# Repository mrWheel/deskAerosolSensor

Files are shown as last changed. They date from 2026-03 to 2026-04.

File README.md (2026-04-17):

# SEN66 Dashboard for CYD ILI9341

<div align="center">
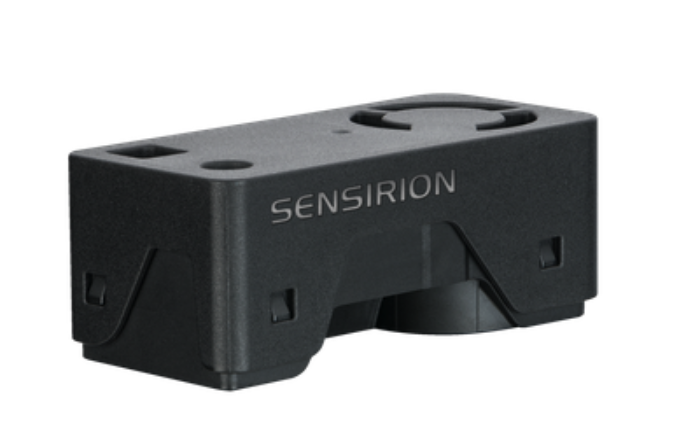
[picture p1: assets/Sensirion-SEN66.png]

</div>

## Disclaimer
This software is developed incrementally. That means I have no clear idea how it works (though it mostly does).

If you have questions about this software, it will probably take you just as long to figure things out as it would take me. So I’d prefer that you investigate it yourself.

Having said that Don’t Even Think About Using It

Seriously. Don’t.

Building this design may injure or kill you during construction, burn your house down while in use, and then—just to be thorough—explode afterward.

This is not a joke. This project involves lethal voltages. If you are not a qualified electronics engineer, close this repository, step away from the soldering iron, and make yourself a cup of tea.

If you decide to ignore all of the above and build it anyway, you do so entirely at your own risk. You are fully responsible for taking proper safety precautions. I take zero responsibility for anything that happens—electrically, mechanically, chemically, spiritually, or otherwise.

Also, full disclosure: I am not a qualified electrical engineer. I provide no guarantees, no warranties, and absolutely no assurance that this design is correct, safe, or suitable for any purpose whatsoever.

## What it is
This PlatformIO project targets a CYD style ESP32 board with an ILI9341 display and a 3x3 LVGL dashboard.
A Desktop device that measures and display the air quality in the room.

<div align="center">
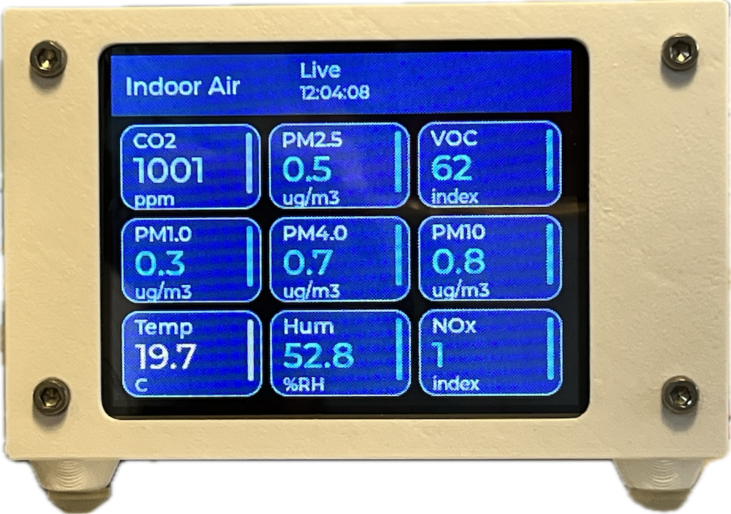
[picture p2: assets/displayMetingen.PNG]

</div>

## Included environments

- `cyd_ili9341`

<div align="center">
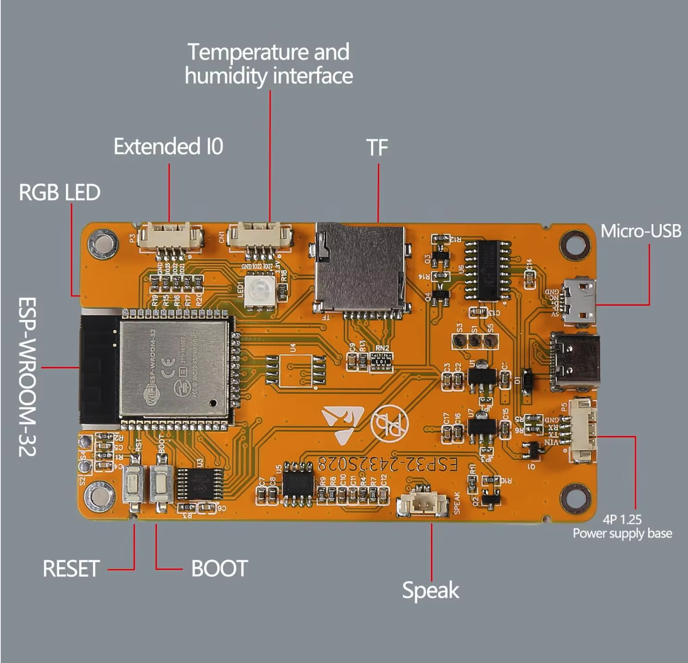
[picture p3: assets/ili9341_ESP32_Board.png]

</div>

  - Main runtime environment for ILI9341
  - Uses the calibrated display configuration
  - `UPDATE_INTERVAL=2500` (milliseconds)
  - `SIMULATION` to show simulated data without using the SEN66

- `ili9341_r4`
  - Display validation environment with `TEST_DISPLAY=1`
  - Shows diagnostic pages (color bars, grid, corner markers, info)

## Display calibration summary

The panel is stable with:

- `CYD_LCD_ROTATION=4`
- `CYD_LCD_PANEL_WIDTH=320`
- `CYD_LCD_PANEL_HEIGHT=240`
- `CYD_LCD_RGB_ORDER=1`

See [ili9341.md](ili9341.md) for full details.

## Sensor wiring for runtime mode

Default I2C pins in `cyd_ili9341`:

- SEN66 VDD -> 3V3
- SEN66 GND -> GND
- SEN66 SDA -> GPIO27
- SEN66 SCL -> GPIO22

<div align="center">
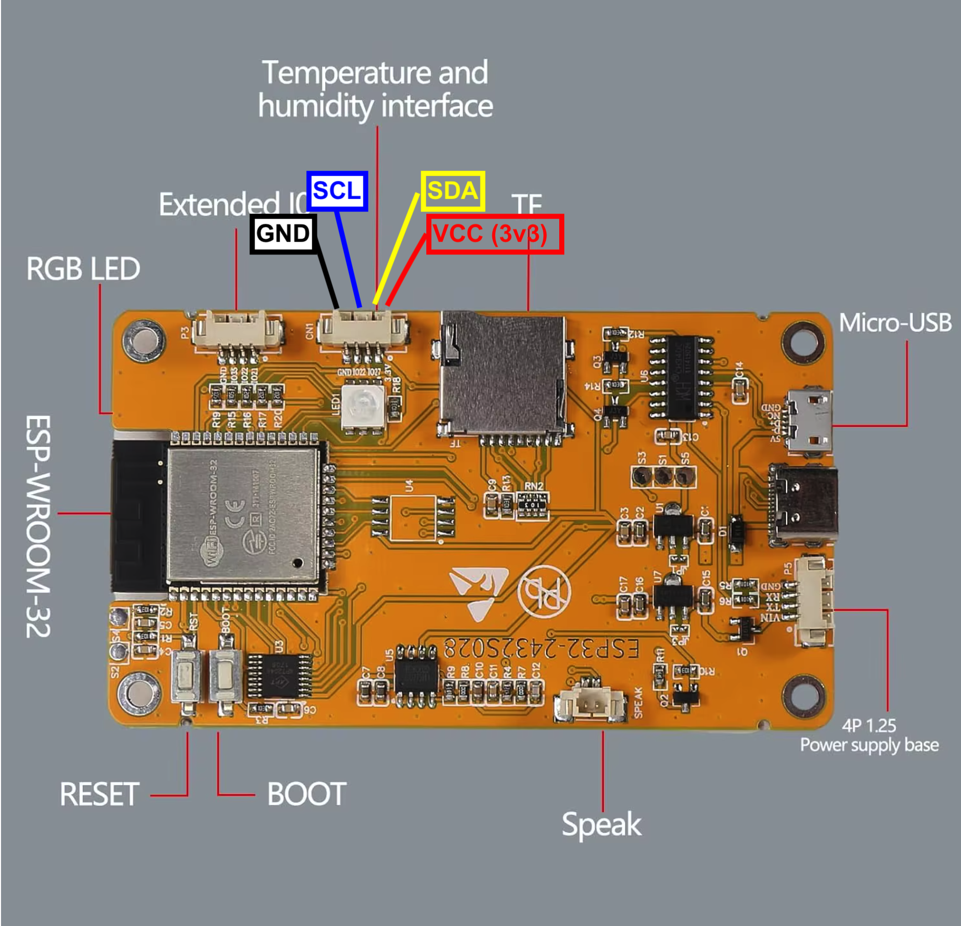
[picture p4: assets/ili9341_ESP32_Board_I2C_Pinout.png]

</div>

Important: on the ILI9341 variant, using GPIO21 for SDA conflicts with the display backlight pin and can make the screen appear black.

## Simulation mode

When `SIMULATION=1` is enabled:

- sensor read logic is skipped
- all nine tiles are updated with synthetic values
- each tile follows a different up/down waveform
- values do not peak at the same time, making color transitions easy to inspect

## Runtime timing

- `UPDATE_INTERVAL` is in milliseconds (ms)
- Set it in `platformio.ini` via build flag, for example:
  - `-D UPDATE_INTERVAL=2500` for 2.5 s
  - `-D UPDATE_INTERVAL=5000` for 5.0 s

The dashboard still shows human-readable time in seconds in the header.

## UI behavior notes

- Header status text uses a fixed position block to avoid left/right jumping when line lengths change.
- The second status line (`Just updated` / `Updated ...`) is tuned to sit close under the first line.
- The existing vertical line at the right side of each tile (LVGL scrollbar part) follows the same color as the tile value.

## MQTT
Measured data is published over MQTT.

WiFi is required before MQTT can connect.

At startup the device first tries stored WiFi credentials. If no credentials are stored, or connection fails, it starts the WiFiManager on-demand captive portal (timeout: 5 minutes).

When the portal starts, the UI and serial output show the AP name to connect to:

- `DAS-a1-2b-3c`

Where `a1`, `2b`, and `3c` are the last three bytes of the ESP32 MAC address.

The WiFi/MQTT portal logic is implemented in:

- `WiFiManagerExt.h`
- `WiFiManagerExt.cpp`

Portal fields:

- MQTT broker URL
- MQTT username (optional)
- MQTT password (optional)
- MQTT broker port (`1883` for plain MQTT, `8883` for TLS)
- MQTT topic (default: AP name + `/data`, for example `DAS-a1-2b-3c/data`)
- MQTT publish interval (ms)

```
{"pm1_0":0.6,"pm2_5":1.0,"pm4_0":1.3,"pm10":1.5,"humidity":52.6,"temperature":17.7,"voc":68,"nox":1,"co2":1372,"timeStamp":"2026-03-28T15:24:41+0100"}
{"pm1_0":0.6,"pm2_5":1.0,"pm4_0":1.3,"pm10":1.5,"humidity":52.6,"temperature":17.7,"voc":68,"nox":1,"co2":1371,"timeStamp":"2026-03-28T15:24:51+0100"}
{"pm1_0":0.6,"pm2_5":1.0,"pm4_0":1.3,"pm10":1.5,"humidity":52.6,"temperature":17.6,"voc":68,"nox":1,"co2":1367,"timeStamp":"2026-03-28T15:25:01+0100"}
```
These values are persisted and shown again as defaults in the portal.
If no topic was saved yet, or the saved topic is empty, the default topic is `DAS-xx-yy-zz/data` based on the last three MAC bytes.

If GPIO0 is held low for longer than 10 seconds, stored WiFi settings are cleared and the device restarts (`ESP.restart()`).

### MQTT payload

Each publish sends one JSON object with the latest sample, for example:

```json
{
  "pm1_0": 7.3,
  "pm2_5": 12.8,
  "pm4_0": 16.2,
  "pm10": 22.1,
  "humidity": 45.6,
  "temperature": 20.4,
  "voc": 103,
  "nox": 84,
  "co2": 721,
  "timestamp": 2026-03-28T15:24:41+0100
}
```

## Build and upload

Examples:

- Build main runtime:
  - `platformio run -e cyd_ili9341`
- Upload main runtime:
  - `platformio run -e cyd_ili9341 --target upload`
- Build display test:
  - `platformio run -e ili9341_r4`

## Dashboard tiles

- CO2
- PM2.5
- VOC
- PM1.0
- PM4.0
- PM10
- Temp
- Hum
- NOx

Tile value colors move from cooler (blue) to warmer tones (red) as badness increases.

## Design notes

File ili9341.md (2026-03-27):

# ILI9341 on CYD (ESP32) - Final Working Notes

This file captures the latest proven display setup used in this repository.

## 1. Hardware profile

- Board class: ESP32 CYD style board with 2.8 inch panel
- Display controller: ILI9341
- SPI host: VSPI
- SPI and control pins:
  - SCLK = 14
  - MOSI = 13
  - MISO = 12
  - DC = 2
  - CS = 15
  - Backlight = 21

## 2. Required panel geometry and orientation

The panel works correctly with these settings:

- panel width = 320
- panel height = 240
- memory width = 320
- memory height = 240
- rotation = 4
- RGB order = true

Without explicit memory width and memory height, the panel can show shifted or wrapped output in some rotation combinations.

## 3. LovyanGFX panel configuration

Use this configuration pattern:

```cpp
auto config = panel.config();
config.pin_cs = 15;
config.pin_rst = -1;
config.pin_busy = -1;

config.panel_width = 320;
config.panel_height = 240;
config.memory_width = 320;
config.memory_height = 240;

config.offset_x = 0;
config.offset_y = 0;
config.offset_rotation = 0;

config.rgb_order = true;
config.invert = false;
```

And set:

```cpp
tft.setRotation(4);
```

## 4. SPI bus settings

Stable settings in this project:

```cpp
auto busCfg = bus.config();
busCfg.spi_host = VSPI_HOST;
busCfg.spi_mode = 0;
busCfg.freq_write = 40000000;
busCfg.freq_read = 16000000;
busCfg.spi_3wire = false;
busCfg.use_lock = true;
busCfg.dma_channel = SPI_DMA_CH_AUTO;
```

## 5. LVGL flush path that worked reliably

The final working flush path uses `pushImage`:

```cpp
tft.startWrite();
tft.pushImage(area->x1, area->y1, width, height, reinterpret_cast<lgfx::rgb565_t*>(colorMap));
tft.endWrite();
```

LVGL resolution is derived from the active display object (`tft.width()`, `tft.height()`).

## 6. Current environments

This repository intentionally keeps two environments:

- `cyd_ili9341`
  - Full dashboard build for ILI9341
  - Currently configured with `SIMULATION=1`
- `ili9341_r4`
  - Display-only test pattern mode (`TEST_DISPLAY=1`)

## 7. SIMULATION mode behavior

With `SIMULATION=1`:

- sensor reading is skipped
- all nine tiles update continuously
- values move slowly up and down
- each tile uses a different period and phase so peaks do not happen at the same time
- serial monitor prints periodic simulation snapshots

## 8. Quick display verification

In `ili9341_r4` test mode, verify:

- color bars are in logical order
- corner markers are in expected corners
- text is readable and not mirrored

## 9. Practical note on borders

A small inactive black edge can still be normal panel dead area near the FPC side and is not always removable in software.

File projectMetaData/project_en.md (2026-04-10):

# Desktop Air Quality Monitor

This project turns an ***Cheap Yellow Display*** into a live indoor air quality 
dashboard using a SEN66 sensor and a color-coded 3x3 tile interface.
It continuously shows particulate matter (PM1.0, PM2.5, PM4.0, PM10), CO2, 
VOC index, NOx index, temperature, and humidity.

A clear startup flow handles connectivity, sensor warm-up, and status 
feedback directly on screen.
If no network is available, a captive WiFi portal allows configuration 
without reflashing.
When configured, measurements can be published as JSON messages to an MQTT 
broker at a chosen interval.
Time synchronization enables reliable timestamps for telemetry and diagnostics.

A simulation mode is included to validate dashboard behavior without physical 
sensor input.

The result is a practical, readable, and deployable desktop monitor for 
real-time environmental awareness.

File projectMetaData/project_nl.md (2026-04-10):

# Desktop Luchtkwaliteit Meter

Dit project maakt met een ***Cheap Yellow Display*** een live dashboard voor
binnenluchtkwaliteit met een SEN66-sensor en een kleurgecodeerde 
3x3 tegelweergave.
Het systeem toont continu fijnstofwaarden (PM1.0, PM2.5, PM4.0, PM10), CO2,
VOC-index, NOx-index, temperatuur en luchtvochtigheid.

Een duidelijke opstartflow begeleidt netwerkverbinding, sensor-opwarming en statusmeldingen rechtstreeks op het scherm.
Als er nog geen netwerk is ingesteld, kan configuratie via een captive WiFi-portaal
gebeuren zonder opnieuw te flashen.
Wanneer geconfigureerd, worden metingen als JSON-berichten naar een MQTT-broker
verstuurd op een instelbaar interval.
Tijdsynchronisatie zorgt voor bruikbare tijdstempels in telemetrie en diagnose.

Er is ook een simulatiemodus voorzien om de dashboardlogica te testen zonder 
fysieke sensorinput.

Het resultaat is een praktisch, leesbaar en inzetbaar desktopmonitoringsysteem 
voor realtime omgevingsinzichten.

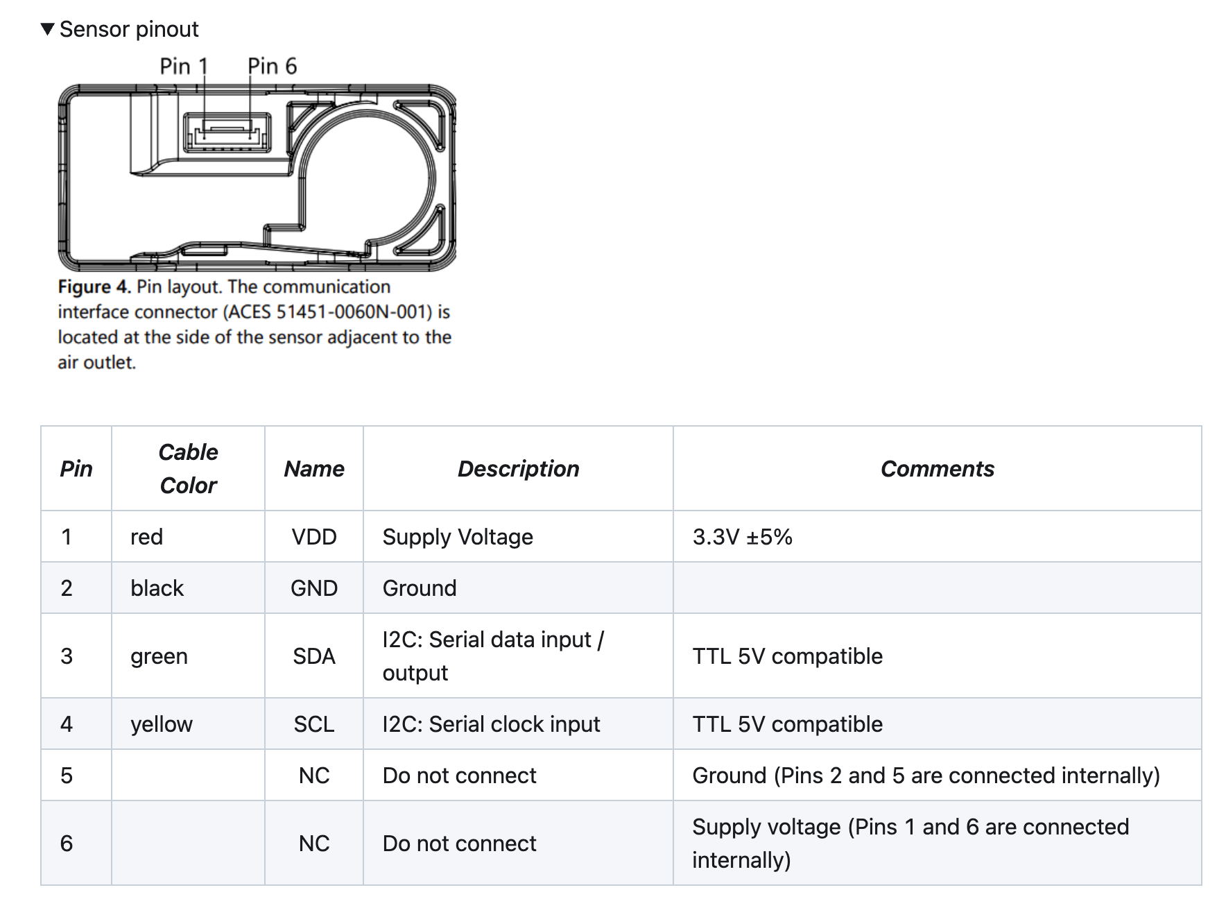
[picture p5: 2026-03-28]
assets/SEN66_Pinout.png

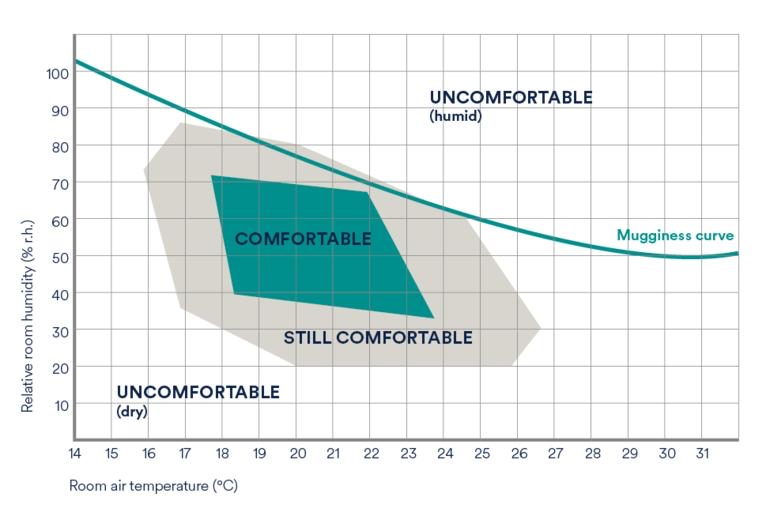
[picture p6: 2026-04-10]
assets/TemperatureConfort.png

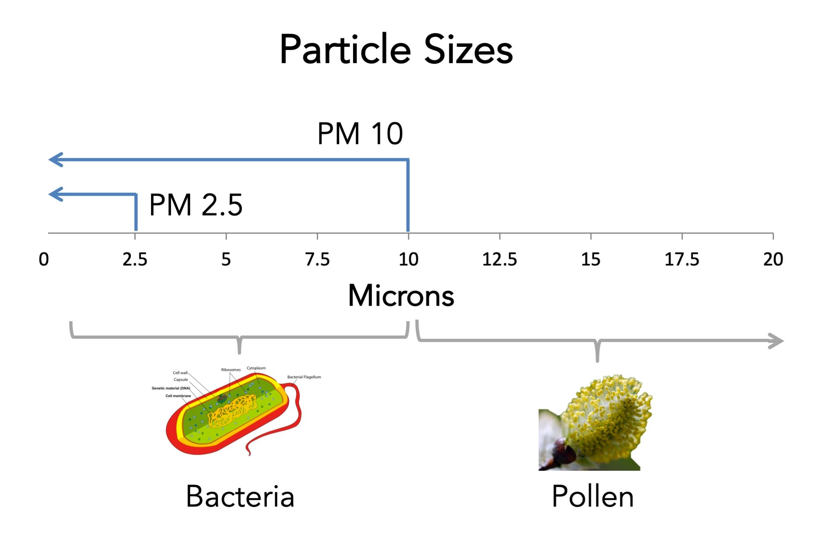
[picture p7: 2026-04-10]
assets/particleSizes.png

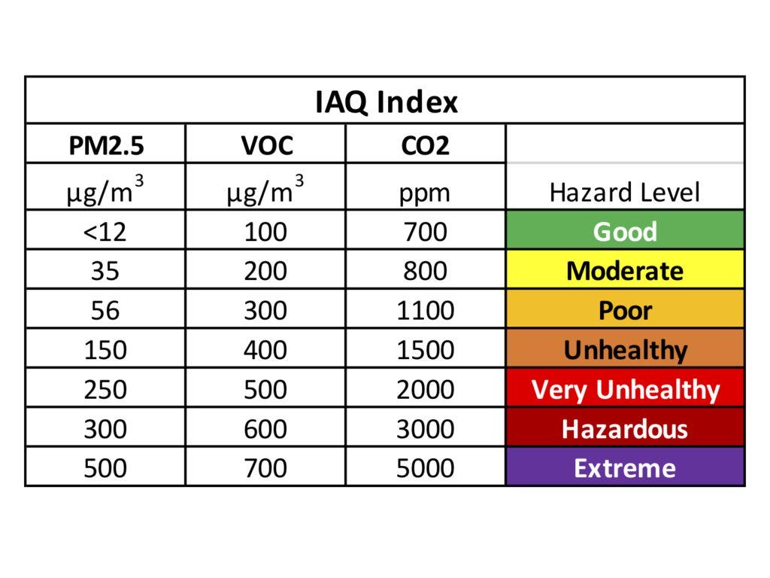
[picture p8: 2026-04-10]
assets/IAQ_Index.png

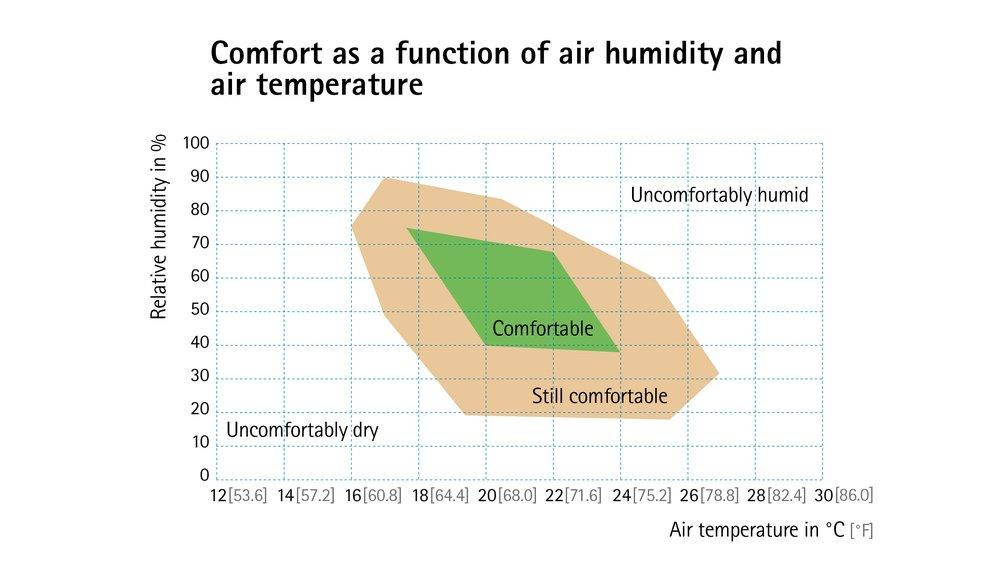
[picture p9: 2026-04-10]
assets/HumidetyConfort.png

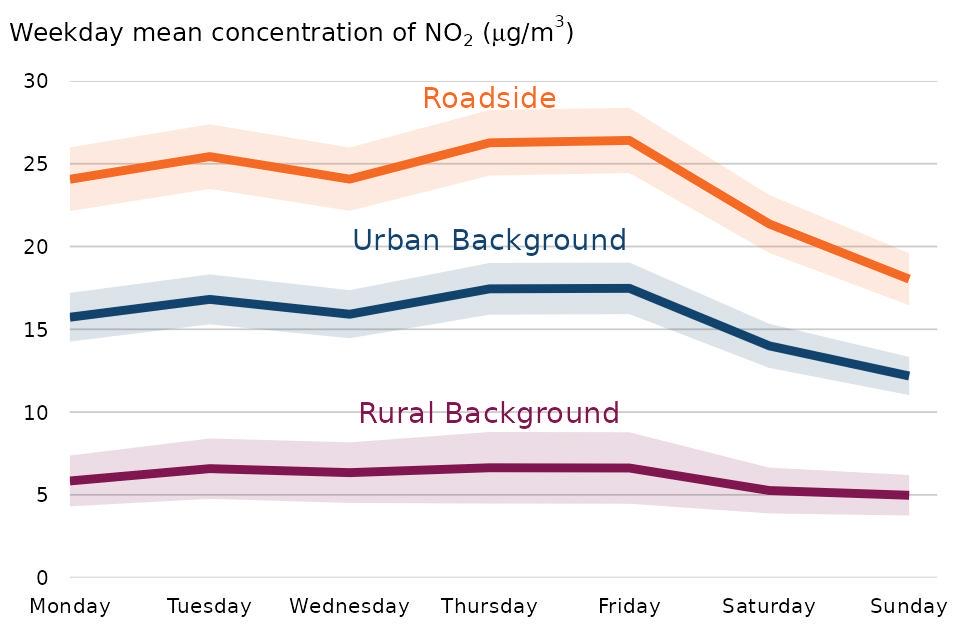
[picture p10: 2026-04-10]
assets/NO2_Index.png

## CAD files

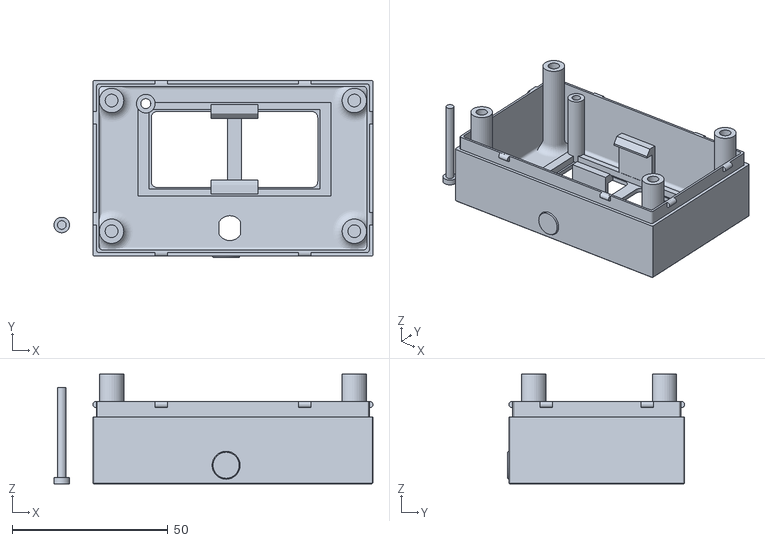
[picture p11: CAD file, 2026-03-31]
3D/deskAerosolSensorBase.stl
102.5 x 57.0 x 35.3

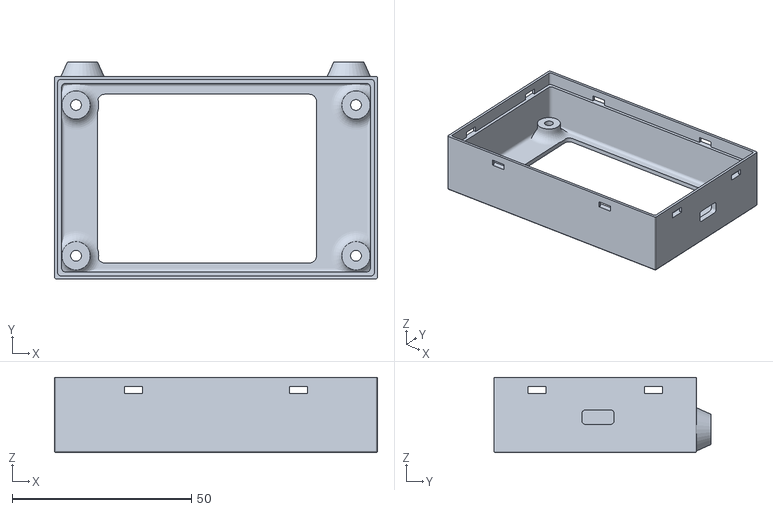
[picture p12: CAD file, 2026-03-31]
3D/deskAerosolSensorLid.stl
90.0 x 60.5 x 21.0

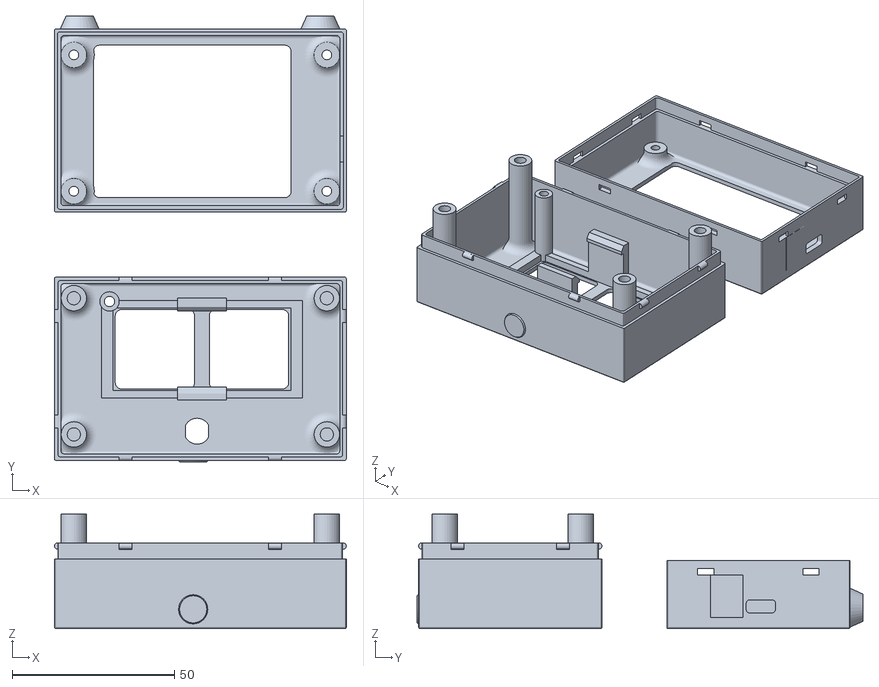
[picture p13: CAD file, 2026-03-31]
3D/deskAerosolSensor.stl
90.1 x 137.5 x 35.3

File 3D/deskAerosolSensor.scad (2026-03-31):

//-----------------------------------------------------------------------
// Yet Another Parameterized Projectbox generator
//
//  This is a box for timerModule HCW-M421
//
//  Version 1.0.0 (2026-02-17)
//
// This design is parameterized based on the size of a PCB.
//
// For many/complex cutoutGrills, you might need to adjust
//  the max number of elements in OpenSCAD:
//
//      Preferences->Advanced->Turn off rendering at 250000 elements
//                                                   ^^^^^^
//
//-----------------------------------------------------------------------


include <./YAPPgenerator_v3.scad>

//---------------------------------------------------------
// This design is parameterized based on the size of a PCB.
//---------------------------------------------------------
// Note: length/lengte refers to X axis, 
//       width/breedte refers to Y axis,
//       height/hoogte refers to Z axis

/*
      padding-back|<------pcb length --->|<padding-front
                            RIGHT
        0    X-axis ---> 
        +----------------------------------------+   ---
        |                                        |    ^
        |                                        |   padding-right 
      Y |                                        |    v
      | |    -5,y +----------------------+       |   ---              
 B    a |         | 0,y              x,y |       |     ^              F
 A    x |         |                      |       |     |              R
 C    i |         |                      |       |     | pcb width    O
 K    s |         |                      |       |     |              N
        |         | 0,0              x,0 |       |     v              T
      ^ |    -5,0 +----------------------+       |   ---
      | |                                        |    padding-left
      0 +----------------------------------------+   ---
        0    X-as --->
                          LEFT
*/


//-- which part(s) do you want to print?
printBaseShell        = true;
printLidShell         = false;
printSwitchExtender   = true;
printDisplayClips     = false;

// ********************************************************************
// The Following will be used as the first element in the pbc array

//Defined here so you can define the "Main" PCB using these if wanted
pcbLength           =  86; // front to back (X axis)
pcbWidth            =  50; // side to side (Y axis)
pcbThickness        = 1.6; 
standoffHeight      = 3.0; //-- How much the PCB needs to be raised from the base to leave room for solderings and whatnot
standoffDiameter    = 3;
standoffPinDiameter = 2.2;
standoffHoleSlack   = 0.2;

//===================================================================
// *** PCBs ***
// Printed Circuit Boards
//-------------------------------------------------------------------
//  Default origin =  yappCoordPCB : yappCoordBoxInside[0,0,0]
//
//  Parameters:
//   Required:
//    p(0) = name
//    p(1) = length
//    p(2) = width
//    p(3) = posx
//    p(4) = posy
//    p(5) = Thickness
//    p(6) = standoff_Height = Height to bottom of PCB from the inside of the base
//             negative measures from inside of the lid to the top of the PCB
//    p(7) = standoff_Diameter
//    p(8) = standoff_PinDiameter
//   Optional:
//    p(9) = standoff_HoleSlack (default to 0.4)

//The following can be used to get PCB values elsewhere in the script - not in pcb definition. 
//If "PCB Name" is omitted then "Main" is used
//  pcbLength           --> pcbLength("PCB Name")
//  pcbWidth            --> pcbWidth("PCB Name")
//  pcbThickness        --> pcbThickness("PCB Name") 
//  standoffHeight      --> standoffHeight("PCB Name") 
//  standoffDiameter    --> standoffDiameter("PCB Name") 
//  standoffPinDiameter --> standoffPinDiameter("PCB Name") 
//  standoffHoleSlack   --> standoffHoleSlack("PCB Name") 

pcb = 
[
  // Default Main PCB - DO NOT REMOVE the "Main" line.
  ["Main",  pcbLength,pcbWidth, 0, 0, pcbThickness
          , standoffHeight
          , standoffDiameter
          , standoffPinDiameter
          , standoffHoleSlack]
];

//-------------------------------------------------------------------                            
//-- padding between pcb and inside wall
paddingFront        = 0;
paddingBack         = 0;
paddingRight        = 0.5;
paddingLeft         = 2;

//-- Edit these parameters for your own box dimensions
wallThickness       = 2.0;
basePlaneThickness  = 1.5;
lidPlaneThickness   = 1.5;

//-- Total height of box = lidPlaneThickness 
//                       + lidWallHeight 
//--                     + baseWallHeight 
//                       + basePlaneThickness
//-- space between pcb and lidPlane :=
//--      (bottonWallHeight+lidWallHeight) - (standoffHeight+pcbThickness)
baseWallHeight      = 25;
lidWallHeight       = 15;

//-- ridge where base and lid off box can overlap
//-- Make sure this isn't less than lidWallHeight
ridgeHeight         = 5.0;
ridgeSlack          = 0.4; // Gap between the inside of the lid and the outside of the base
//New in v3.3.7 
ridgeGap            = 0.5; // Gap between the bottom of the base ridge and the bottom of the lid when assembled.
roundRadius         = 0.5;

// Box Types are 0-4 with 0 as the default
// 0 = All edges rounded with radius (roundRadius) above
// 1 = All edges sqrtuare
// 2 = All edges chamfered by (roundRadius) above 
// 3 = Square top and bottom edges (the ones that touch the build plate) and rounded vertical edges
// 4 = Square top and bottom edges (the ones that touch the build plate) and chamfered vertical edges
// 5 = Chanfered top and bottom edges (the ones that touch the build plate) and rounded vertical edges
boxType             = 0; // Default type 0

// Set the layer height of your printer
printerLayerHeight  = 0.2;


//---------------------------
//--     C O N T R O L     --
//---------------------------
// -- Render --
renderQuality             = 8;          //-> from 1 to 32, Default = 8
$fn=30;
// --Preview --
previewQuality            = 5;          //-> from 1 to 32, Default = 5
showSideBySide            = true;       //-> Default = true
onLidGap                  = 0;  // tip don't override to animate the lid opening
colorLid                  = "YellowGreen";   
alphaLid                  = 1;
colorBase                 = "BurlyWood";
alphaBase                 = 1;
hideLidWalls              = true;      //-> Remove the walls from the lid : only if preview and showSideBySide=true 
hideBaseWalls             = true;      //-> Remove the walls from the base : only if preview and showSideBySide=true  
showOrientation           = true;       //-> Show the Front/Back/Left/Right labels : only in preview
showPCB                   = false;      //-> Show the PCB in red : only in preview 
showSwitches              = false;      //-> Show the switches (for pushbuttons) : only in preview 
showButtonsDepressed      = false;      //-> Should the buttons in the Lid On view be in the pressed position
showOriginCoordBox        = false;      //-> Shows red bars representing the origin for yappCoordBox : only in preview 
showOriginCoordBoxInside  = false;      //-> Shows blue bars representing the origin for yappCoordBoxInside : only in preview 
showOriginCoordPCB        = false;      //-> Shows blue bars representing the origin for yappCoordBoxInside : only in preview 
showMarkersPCB            = false;      //-> Shows black bars corners of the PCB : only in preview 
showMarkersCenter         = false;      //-> Shows magenta bars along the centers of all faces  
inspectX                  = 0;          //-> 0=none (>0 from Back)
inspectY                  = 0;          //-> 0=none (>0 from Right)
inspectZ                  = 0;          //-> 0=none (>0 from Bottom)
inspectXfromBack          = true;       //-> View from the inspection cut foreward
inspectYfromLeft          = true;       //-> View from the inspection cut to the right
inspectZfromBottom        = true;       //-> View from the inspection cut up
//---------------------------
//--     C O N T R O L     --
//---------------------------

//-------------------------------------------------------------------
//-------------------------------------------------------------------
// Start of Debugging config (used if not overridden in template)
// ------------------------------------------------------------------
// ------------------------------------------------------------------
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

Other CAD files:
3D/YAPP_Template_v3.scad
3D/YAPPgenerator_v3.scad

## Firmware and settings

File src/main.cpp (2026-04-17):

/*** Last Changed: 2026-04-17 - 08:38 ***/
#include <Arduino.h>
#include <Wire.h>
#include <lvgl.h>
#include <math.h>
#include <time.h>
#include <WiFi.h>
#include <WiFiClientSecure.h>
#include <PubSubClient.h>
#include "appConfig.h"
#include "dashboardUi.h"
#include "displayDriver.h"
#include "sensorReader.h"
#include "WiFiManagerExt.h"

const char* PROG_VERSION = "v1.1.1";

//--- Global objects
static DashboardUi dashboardUi;
static DisplayDriver displayDriver;
static SensorReader sensorReader;
static WiFiManagerExt wifiManagerExt;
static SensorData sensorData = {};
static bool sensorOnline = false;
static bool mqttEnabled = false;
static bool wifiReady = false;
static bool tilesVisible = false;
static uint32_t sensorStartMs = 0;
static uint32_t lastSensorReadMs = 0;
static uint32_t lastSensorRetryMs = 0;
static uint32_t lastMqttConnectTryMs = 0;
static uint32_t lastMqttPublishMs = 0;
static uint32_t lastTimeSyncTryMs = 0;
static uint32_t mqttStatusFlashUntilMs = 0;
static constexpr uint32_t kSensorRetryIntervalMs = 5000;
static constexpr uint32_t kMqttRetryIntervalMs = 5000;
static constexpr uint32_t kTimeSyncRetryMs = 60000;
static constexpr uint32_t kMqttStatusFlashMs = 800;
static bool timeSynced = false;

static WiFiClient mqttClientPlain;
static WiFiClientSecure mqttClientSecure;
static PubSubClient mqttClient(mqttClientPlain);

static void updateLastUpdateText(uint32_t ageMs);

//--- Keep the initialization header status and time up to date
static void refreshInitializationHeader()
{
  dashboardUi.setStatusText("Initialisation");
  updateLastUpdateText(0);

} //   refreshInitializationHeader()

//--- Show an initialization status screen below the persistent header
static void showInitializationScreen(const char* titleText, const char* line1Text, const char* line2Text)
{
  refreshInitializationHeader();
  dashboardUi.showFullScreenMessage(titleText, line1Text, line2Text);

} //   showInitializationScreen()

//--- Try to synchronize ESP32 clock over NTP while WiFi is connected
static bool syncTimeFromNtp()
{
  configTzTime("CET-1CEST,M3.5.0/2,M10.5.0/3", "pool.ntp.org", "time.nist.gov", "time.google.com");

  const uint32_t startedMs = millis();
  while ((millis() - startedMs) < 10000)
  {
    if (time(nullptr) > 1700000000)
    {
      timeSynced = true;
      Serial.println("NTP time synchronized");
      return true;
    }

    displayDriver.loop();
    wifiManagerExt.loop();
    delay(50);
  }

  timeSynced = false;
  Serial.println("Warning: NTP time sync failed");
  return false;
}

//--- Ensure time sync is retried periodically until successful
static void ensureTimeSync(uint32_t now)
{
  if (!wifiManagerExt.isWifiConnected() || timeSynced)
  {
    return;
  }

  if ((now - lastTimeSyncTryMs) < kTimeSyncRetryMs)
  {
    return;
  }

  lastTimeSyncTryMs = now;
  syncTimeFromNtp();
}

//--- Format current local time as ISO8601 (Europe/Amsterdam, with numeric offset)
static bool makeIsoTimestamp(char* out, size_t outSize)
{
  const time_t now = time(nullptr);
  if (now <= 0)
  {
    return false;
  }

  struct tm localTm;
  localtime_r(&now, &localTm);
  return strftime(out, outSize, "%Y-%m-%dT%H:%M:%S%z", &localTm) > 0;
}

//--- Show MQTT text briefly in the top-right status label on successful publish
static void updateMqttStatusFlash(uint32_t now)
{
  if (mqttStatusFlashUntilMs == 0)
  {
    return;
  }

  if (now < mqttStatusFlashUntilMs)
  {
    return;
  }

  mqttStatusFlashUntilMs = 0;
  dashboardUi.setMqttIndicator(false);
}

//--- Update the dashboard when WiFi manager opens the captive portal
static void onPortalStatus(const char* statusText, const char* detailText)
{
  const bool portalActive = (statusText != nullptr) && (strstr(statusText, "portal") != nullptr);
  const char* line2 = portalActive ? "Open 192.168.4.1 for portal" : "";
  showInitializationScreen(statusText, detailText, line2);
  displayDriver.loop();
  delay(20);
}

//--- Keep LVGL active while a full-screen status message should remain visible
static void showTransientStatusScreen(const char* titleText, const char* line1Text, const char* line2Text, uint32_t holdMs)
{
  showInitializationScreen(titleText, line1Text, line2Text);
  const uint32_t startMs = millis();
  while ((millis() - startMs) < holdMs)
  {
    refreshInitializationHeader();
    displayDriver.loop();
    wifiManagerExt.loop();
    delay(5);
  }
}

//--- Create a stable MQTT client id from the chip MAC
static String buildMqttClientId()
{
  uint8_t mac[6] = {0};
  WiFi.macAddress(mac);

  char clientId[32];
  snprintf(
      clientId,
      sizeof(clientId),
      "deskAerosol-%02x%02x%02x",
      static_cast<unsigned int>(mac[3]),
      static_cast<unsigned int>(mac[4]),
      static_cast<unsigned int>(mac[5]));
  return String(clientId);
}

//--- Configure the MQTT transport and endpoint based on stored portal settings
static void configureMqttEndpoint()
{
  const MqttRuntimeConfig& cfg = wifiManagerExt.mqttConfig();
  const bool useTls = (cfg.brokerPort == 8883);

  if (useTls)
  {
    mqttClientSecure.setInsecure();
    mqttClient.setClient(mqttClientSecure);
  }
  else
  {
    mqttClient.setClient(mqttClientPlain);
  }

  mqttClient.setServer(cfg.brokerUrl.c_str(), cfg.brokerPort);
}

//--- Keep the MQTT connection alive with periodic reconnect attempts
static void maintainMqttConnection(uint32_t now)
{
  if (!mqttEnabled)
  {
    return;
  }

  if (!wifiManagerExt.isWifiConnected())
  {
    return;
  }

  if (mqttClient.connected())
  {
    return;
  }

  if ((now - lastMqttConnectTryMs) < kMqttRetryIntervalMs)
  {
    return;
  }

  lastMqttConnectTryMs = now;
  const MqttRuntimeConfig& cfg = wifiManagerExt.mqttConfig();
  const String clientId = buildMqttClientId();

  bool connected = false;
  if (cfg.username.length() == 0)
  {
    connected = mqttClient.connect(clientId.c_str());
  }
  else
  {
    connected = mqttClient.connect(clientId.c_str(), cfg.username.c_str(), cfg.password.c_str());
  }

  if (connected)
  {
    Serial.println("MQTT connected");
    return;
  }

  Serial.printf("MQTT connect failed (state=%d)\n", mqttClient.state());
}

//--- Publish one sensor sample in JSON format to the configured MQTT topic
static void publishMqttSampleIfDue(const SensorData& data, uint32_t now)
{
  if (!mqttEnabled || !data.valid)
  {
    return;
  }

  const MqttRuntimeConfig& cfg = wifiManagerExt.mqttConfig();
  if ((now - lastMqttPublishMs) < cfg.publishIntervalMs)
  {
    return;
  }

  if (!mqttClient.connected())
  {
    return;
  }

  if (!timeSynced)
  {
    ensureTimeSync(now);
    if (!timeSynced)
    {
      return;
    }
  }

  char timeStamp[32];
  if (!makeIsoTimestamp(timeStamp, sizeof(timeStamp)))
  {
    return;
  }

  char payload[320];
  snprintf(
      payload,
      sizeof(payload),
      "{\"pm1_0\":%.1f,\"pm2_5\":%.1f,\"pm4_0\":%.1f,\"pm10\":%.1f,\"humidity\":%.1f,\"temperature\":%.1f,\"voc\":%.0f,\"nox\":%.0f,\"co2\":%u,\"timeStamp\":\"%s\"}",
      data.pm1p0,
      data.pm2p5,
      data.pm4p0,
      data.pm10p0,
      data.humidity,
      data.temperature,
      data.vocIndex,
      data.noxIndex,
      static_cast<unsigned int>(data.co2),
      timeStamp);

  if (mqttClient.publish(cfg.topic.c_str(), payload))
  {
    lastMqttPublishMs = now;
    mqttStatusFlashUntilMs = now + kMqttStatusFlashMs;
    dashboardUi.setMqttIndicator(true);
  }
}

//--- Initialize WiFi (saved AP or portal) and prepare MQTT connectivity
static bool initConnectivity()
{
  wifiManagerExt.setPortalStatusCallback(onPortalStatus);
  showInitializationScreen("WiFi setup", "Trying saved credentials...", "");
  displayDriver.loop();

  if (!wifiManagerExt.beginAndConnect())
  {
    showInitializationScreen("WiFi failed", "No credentials or no AP connection", "Portal timeout after 5 minutes");
    mqttEnabled = false;
    return false;
  }

  const String hostName = wifiManagerExt.portalSsidString();
  const String ipOnly = wifiManagerExt.localIpString();

  char line2[128];
  snprintf(line2, sizeof(line2), "IP: %s\nNTP: synchronizing...", ipOnly.c_str());
  showInitializationScreen("WiFi connected", hostName.c_str(), line2);
  displayDriver.loop();

  syncTimeFromNtp();

  char ntpText[32];
  if (makeIsoTimestamp(ntpText, sizeof(ntpText)))
  {
    snprintf(line2, sizeof(line2), "IP: %s\nNTP: %s", ipOnly.c_str(), ntpText);
  }
  else
  {
    snprintf(line2, sizeof(line2), "IP: %s\nNTP: unavailable", ipOnly.c_str());
  }
  showTransientStatusScreen("WiFi connected", hostName.c_str(), line2, 2500);

  const MqttRuntimeConfig& cfg = wifiManagerExt.mqttConfig();
  const bool mqttConfigValid = (cfg.brokerUrl.length() > 0) && (cfg.topic.length() > 0);

  if (!mqttConfigValid)
  {
    Serial.printf(
        "MQTT disabled: brokerLen=%u topicLen=%u\n",
        static_cast<unsigned int>(cfg.brokerUrl.length()),
        static_cast<unsigned int>(cfg.topic.length()));
    showInitializationScreen("WiFi only mode", "MQTT is not configured", "Sensor dashboard will continue");
    displayDriver.loop();
    mqttEnabled = false;
    return true;
  }

  configureMqttEndpoint();
  mqttEnabled = true;
  return true;
}

//--- Generate a 0..1 triangle wave from a monotonically increasing phase
static float triangle01(float phase)
{
  float wrapped = phase - floorf(phase);
  if (wrapped < 0.5f)
  {
    return wrapped * 2.0f;
  }
  return (1.0f - wrapped) * 2.0f;

} //   triangle01()

//--- Advance simulated sensor values and push them to the dashboard
static void updateSimulationUi()
{
  static uint32_t lastUpdateMs = 0;
  static uint32_t updateCounter = 0;
  const uint32_t now = millis();

  if ((now - lastUpdateMs) < kSensorUpdateIntervalMs)
  {
    return;
  }

  lastUpdateMs = now;
  ++updateCounter;

  const float t = static_cast<float>(updateCounter);

  // Different periods and phase offsets keep tiles from peaking at the same time.
  const float pm1Norm = triangle01(t / 31.0f + 0.10f);
  const float pm25Norm = triangle01(t / 37.0f + 0.24f);
  const float pm4Norm = triangle01(t / 43.0f + 0.38f);
  const float pm10Norm = triangle01(t / 47.0f + 0.55f);
  const float tempNorm = triangle01(t / 53.0f + 0.08f);
  const float humNorm = triangle01(t / 41.0f + 0.67f);
  const float co2Norm = triangle01(t / 59.0f + 0.32f);
  const float vocNorm = triangle01(t / 29.0f + 0.79f);
  const float noxNorm = triangle01(t / 35.0f + 0.46f);

  auto remap = [](float v, float minValue, float maxValue) -> float
  {
    return minValue + v * (maxValue - minValue);
  };

  SensorData sim = {};
  sim.pm1p0 = remap(pm1Norm, 2.0f, 95.0f);
  sim.pm2p5 = remap(pm25Norm, 4.0f, 130.0f);
  sim.pm4p0 = remap(pm4Norm, 5.0f, 160.0f);
  sim.pm10p0 = remap(pm10Norm, 8.0f, 220.0f);
  sim.temperature = remap(tempNorm, 18.5f, 33.5f);
  sim.humidity = remap(humNorm, 32.0f, 92.0f);
  sim.co2 = static_cast<uint16_t>(remap(co2Norm, 420.0f, 2200.0f));
  sim.vocIndex = remap(vocNorm, 35.0f, 360.0f);
  sim.noxIndex = remap(noxNorm, 30.0f, 330.0f);
  sim.valid = true;
  sim.sampleAgeMs = 0;

  dashboardUi.setStatusText("SIMULATION");
  dashboardUi.showSensorData(sim);

  char updateText[64];
  snprintf(updateText, sizeof(updateText), "SIM update #%lu", static_cast<unsigned long>(updateCounter));
  dashboardUi.setLastUpdateText(updateText);

  if ((updateCounter % 4) == 0)
  {
    Serial.printf(
        "[STEP 9] SIM #%lu CO2=%u PM2.5=%.1f PM10=%.1f T=%.1f RH=%.1f VOC=%.0f NOx=%.0f\n",
        static_cast<unsigned long>(updateCounter),
        static_cast<unsigned int>(sim.co2),
        sim.pm2p5,
        sim.pm10p0,
        sim.temperature,
        sim.humidity,
        sim.vocIndex,
        sim.noxIndex);
  }

} //   updateSimulationUi()

//--- Print a numbered boot-step message to the serial console
static void logStep(uint8_t step, const char* text)
{
  Serial.printf("[STEP %u] %s\n", static_cast<unsigned int>(step), text);
}

//--- Format and display the last-update text
static void updateLastUpdateText(uint32_t ageMs)
{
  (void)ageMs;
  char buffer[64];
  const time_t now = time(nullptr);
  if (now > 0)
  {
    struct tm localTm;
    localtime_r(&now, &localTm);
    if (strftime(buffer, sizeof(buffer), "%H:%M:%S", &localTm) == 0)
    {
      snprintf(buffer, sizeof(buffer), "Time unavailable");
    }
  }
  else
  {
    snprintf(buffer, sizeof(buffer), "Time not synced");
  }
  dashboardUi.setLastUpdateText(buffer);

} //   updateLastUpdateText()

//--- Show sensor-offline status and periodic reconnect information
static void updateSensorOfflineStatus(uint32_t now)
{
  const uint32_t elapsedSinceRetry = now - lastSensorRetryMs;
  uint32_t retryInMs = 0;

  if (elapsedSinceRetry < kSensorRetryIntervalMs)
  {
    retryInMs = kSensorRetryIntervalMs - elapsedSinceRetry;
  }

  const uint32_t retryInSeconds = (retryInMs + 999) / 1000;
  char buffer[64];
  snprintf(buffer, sizeof(buffer), "Sensor offline, retry in %lu s", static_cast<unsigned long>(retryInSeconds));
  dashboardUi.showSensorError("No SEN66 connected");
  dashboardUi.setLastUpdateText(buffer);

} //   updateSensorOfflineStatus()

//--- Print one full line with all measured values for debugging
static void logSensorData(const SensorData& data)
{
  Serial.printf(
      "PM1=%.1f PM2.5=%.1f PM4=%.1f PM10=%.1f RH=%.1f T=%.1f VOC=%.0f NOx=%.0f CO2=%u\n",
      data.pm1p0,
      data.pm2p5,
      data.pm4p0,
      data.pm10p0,
      data.humidity,
      data.temperature,
      data.vocIndex,
      data.noxIndex,
      static_cast<unsigned int>(data.co2));

} //   logSensorData()

//--- Perform one timed sensor update and refresh the dashboard
static void updateSensorAndUi()
{
  const uint32_t now = millis();
  enum class RuntimePhase : uint8_t
  {
    Offline = 0,
    Warmup = 1,
    WaitingNext = 2,
    Reading = 3
  };
  static RuntimePhase lastPhase = RuntimePhase::Reading;

  auto setPhase = [&](RuntimePhase phase, const char* text)
  {
    if (phase != lastPhase)
    {
      lastPhase = phase;
      Serial.printf("[STEP 9] %s\n", text);
    }
  };

  if (!sensorOnline)
  {
    setPhase(RuntimePhase::Offline, "Sensor offline / retrying");
    updateSensorOfflineStatus(now);

    if ((now - lastSensorRetryMs) < kSensorRetryIntervalMs)
    {
      return;
    }

    lastSensorRetryMs = now;
    sensorOnline = sensorReader.begin();

    if (!sensorOnline)
    {
      return;
    }

    sensorStartMs = now;
    lastSensorReadMs = now;
    tilesVisible = false;
    const String ipLine = String("IP: ") + wifiManagerExt.localIpString();

    char ntpText[32];
    const bool hasNtp = makeIsoTimestamp(ntpText, sizeof(ntpText));
    char ntpLine[48];
    if (hasNtp)
    {
      snprintf(ntpLine, sizeof(ntpLine), "NTP: %s", ntpText);
    }
    else
    {
      snprintf(ntpLine, sizeof(ntpLine), "NTP: synchronizing...");
    }

    char line2[96];
    snprintf(
        line2,
        sizeof(line2),
        "%s\n30 s remaining",
        ntpLine);

    showInitializationScreen("Warming up SEN66", ipLine.c_str(), line2);
    Serial.println("SEN66 connected after retry");
    return;
  }

  if ((now - sensorStartMs) < kSensorWarmupMs)
  {
    setPhase(RuntimePhase::Warmup, "Sensor warmup");
    const uint32_t elapsedMs = now - sensorStartMs;
    const uint32_t remainingMs = (elapsedMs < kSensorWarmupMs) ? (kSensorWarmupMs - elapsedMs) : 0;
    const uint32_t remainingSec = (remainingMs + 999) / 1000;

    const String ipLine = String("IP: ") + wifiManagerExt.localIpString();
    char ntpText[32];
    const bool hasNtp = makeIsoTimestamp(ntpText, sizeof(ntpText));
    char ntpLine[48];
    if (hasNtp)
    {
      snprintf(ntpLine, sizeof(ntpLine), "NTP: %s", ntpText);
    }
    else
    {
      snprintf(ntpLine, sizeof(ntpLine), "NTP: synchronizing...");
    }

    char line2[96];
    snprintf(
        line2,
        sizeof(line2),
        "%s\n%lu s remaining",
        ntpLine,
        static_cast<unsigned long>(remainingSec));
    showInitializationScreen("Warming up SEN66", ipLine.c_str(), line2);
    return;
  }

  if (!tilesVisible)
  {
    tilesVisible = true;
    dashboardUi.showBooting();
  }

  if ((now - lastSensorReadMs) < kSensorUpdateIntervalMs)
  {
    setPhase(RuntimePhase::WaitingNext, "Waiting for next sensor sample");
    updateLastUpdateText(now - lastSensorReadMs);
    return;
  }

  setPhase(RuntimePhase::Reading, "Reading sensor sample");
  lastSensorReadMs = now;
  sensorData.sampleAgeMs = 0;

  if (!sensorReader.read(sensorData))
  {
    dashboardUi.showSensorError("I2C read failed");
    return;
  }

  logSensorData(sensorData);
  dashboardUi.showSensorData(sensorData);
  updateLastUpdateText(0);
  publishMqttSampleIfDue(sensorData, now);

} //   updateSensorAndUi()

//--- Initialize display and build the dashboard screen
static bool initDisplayAndUi()
{
  logStep(1, "Initialize display driver");

  if (!displayDriver.begin())
  {
    Serial.println("Error: Display initialization failed");
    return false;
  }

  logStep(2, "Display init OK");

#if !defined(TEST_DISPLAY)
  logStep(3, "Build Dashboard UI objects");
  dashboardUi.begin();
  logStep(4, "Dashboard UI ready");
#endif
  return true;

} //   initDisplayAndUi()

//--- Initialize the external SEN66 sensor on the custom I2C bus
static void initSensor()
{
  sensorStartMs = millis();
  lastSensorRetryMs = sensorStartMs;
  sensorOnline = sensorReader.begin();

  if (!sensorOnline)
  {
    Serial.println("Warning: SEN66 not detected, dashboard continues without sensor");
  }

} //   initSensor()

//--- Arduino setup entry point
void setup()
{
  Serial.begin(115200);
  delay(200);
  randomSeed(static_cast<uint32_t>(micros()));

  Serial.println();
  Serial.println("Starting SEN66 dashboard for CYD");
#if defined(CYD_VARIANT_ST7789)
  Serial.println("Display variant: ST7789");
#else
  Serial.println("Display variant: ILI9341");
#endif
  Serial.printf("I2C SDA=%u SCL=%u\n", kI2cSdaPin, kI2cSclPin);
  logStep(0, "Boot sequence start");

  if (!initDisplayAndUi())
  {
    while (true)
    {
      delay(1000);
    }
  }

#if defined(TEST_DISPLAY)
  logStep(5, "Mode TEST_DISPLAY");
  Serial.println("TEST_DISPLAY enabled");
  Serial.println("Display diagnostic pattern is running");
  return;
#endif

#if defined(SIMULATION)
  logStep(5, "Mode SIMULATION");
  Serial.println("Sensor read disabled, synthetic values enabled");
  dashboardUi.showBooting();
  logStep(6, "Dashboard boot screen rendered");
  logStep(7, "Start SIMULATION update loop");
  return;
#endif

  logStep(5, "Mode FULL_RUNTIME");
  showInitializationScreen("Starting", "Preparing connectivity...", "");
  logStep(6, "WiFi status screen rendered");
  logStep(7, "Initialize WiFi + MQTT");
  wifiReady = initConnectivity();

  if (!wifiReady)
  {
    logStep(8, "WiFi not connected, waiting on status screen");
    return;
  }

  const String ipLine = String("IP: ") + wifiManagerExt.localIpString();
  char ntpText[32];
  const bool hasNtp = makeIsoTimestamp(ntpText, sizeof(ntpText));
  char ntpLine[48];
  if (hasNtp)
  {
    snprintf(ntpLine, sizeof(ntpLine), "NTP: %s", ntpText);
  }
  else
  {
    snprintf(ntpLine, sizeof(ntpLine), "NTP: synchronizing...");
  }

  char warmupLine2[96];
  snprintf(
      warmupLine2,
      sizeof(warmupLine2),
      "%s\n30 s remaining",
      ntpLine);
  showInitializationScreen("Warming up SEN66", ipLine.c_str(), warmupLine2);
  logStep(8, "Warmup screen rendered");
  logStep(9, "Initialize sensor");
  initSensor();
  logStep(10, "Sensor init completed");

} //   setup()

//--- Arduino main loop entry point
void loop()
{
#if defined(TEST_DISPLAY)
  displayDriver.runTestPattern();
  delay(5);
  return;
#endif

#if defined(SIMULATION)
  displayDriver.loop();
  wifiManagerExt.loop();
  updateSimulationUi();
  delay(5);
  return;
#endif

  if (!wifiReady)
  {
    displayDriver.loop();
    wifiManagerExt.loop();
    delay(5);
    return;
  }

  displayDriver.loop();
  wifiManagerExt.loop();
  ensureTimeSync(millis());
  maintainMqttConnection(millis());
  mqttClient.loop();
  updateSensorAndUi();
  updateMqttStatusFlash(millis());
  delay(5);

} //   loop()

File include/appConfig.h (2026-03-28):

#pragma once

#include <Arduino.h>

//--- Select I2C pins for the external SEN66 sensor
#ifndef CYD_I2C_SDA_PIN
#define CYD_I2C_SDA_PIN 27
#endif

#ifndef CYD_I2C_SCL_PIN
#define CYD_I2C_SCL_PIN 22
#endif

static constexpr uint8_t kI2cSdaPin = CYD_I2C_SDA_PIN;
static constexpr uint8_t kI2cSclPin = CYD_I2C_SCL_PIN;
static constexpr uint8_t kSen66I2cAddress = 0x6B;

//--- Dashboard timing
static constexpr uint32_t kSensorWarmupMs = 30000;

#ifndef UPDATE_INTERVAL
#define UPDATE_INTERVAL 5000
#endif
static constexpr uint32_t kSensorUpdateIntervalMs = static_cast<uint32_t>(UPDATE_INTERVAL);

//--- Display configuration
#ifndef CYD_LCD_ROTATION
#define CYD_LCD_ROTATION 1
#endif

#ifndef CYD_LCD_OFFSET_X
#define CYD_LCD_OFFSET_X 0
#endif

#ifndef CYD_LCD_OFFSET_Y
#define CYD_LCD_OFFSET_Y 0
#endif

#ifndef CYD_LCD_RGB_ORDER
#define CYD_LCD_RGB_ORDER 0
#endif

#ifndef CYD_LCD_INVERT
#define CYD_LCD_INVERT 0
#endif

#ifndef CYD_LCD_PANEL_WIDTH
#define CYD_LCD_PANEL_WIDTH 240
#endif

#ifndef CYD_LCD_PANEL_HEIGHT
#define CYD_LCD_PANEL_HEIGHT 320
#endif

#ifndef CYD_LCD_SPI_WRITE_HZ
#define CYD_LCD_SPI_WRITE_HZ 40000000
#endif

#ifndef CYD_LCD_SPI_READ_HZ
#define CYD_LCD_SPI_READ_HZ 16000000
#endif

static constexpr uint16_t kScreenWidth = 320;
static constexpr uint16_t kScreenHeight = 240;
static constexpr uint8_t kDisplayRotation = CYD_LCD_ROTATION;
static constexpr int16_t kDisplayOffsetX = CYD_LCD_OFFSET_X;
static constexpr int16_t kDisplayOffsetY = CYD_LCD_OFFSET_Y;
static constexpr bool kDisplayRgbOrder = (CYD_LCD_RGB_ORDER != 0);
static constexpr bool kDisplayInvert = (CYD_LCD_INVERT != 0);
static constexpr uint16_t kDisplayPanelWidth = CYD_LCD_PANEL_WIDTH;
static constexpr uint16_t kDisplayPanelHeight = CYD_LCD_PANEL_HEIGHT;
static constexpr uint32_t kDisplaySpiWriteHz = CYD_LCD_SPI_WRITE_HZ;
static constexpr uint32_t kDisplaySpiReadHz = CYD_LCD_SPI_READ_HZ;

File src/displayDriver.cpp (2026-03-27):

#include "displayDriver.h"
#include "appConfig.h"
#include <esp_timer.h>
#include <esp_heap_caps.h>

DisplayDriver::CydDisplay DisplayDriver::tft;
lv_disp_draw_buf_t DisplayDriver::drawBuffer;
lv_disp_drv_t DisplayDriver::displayDriver;
lv_color_t* DisplayDriver::frameBuffer = nullptr;
esp_timer_handle_t DisplayDriver::tickTimer = nullptr;

//--- Configure the CYD display controller, SPI bus and backlight
DisplayDriver::CydDisplay::CydDisplay()
{
  {
    auto config = bus.config();
    config.spi_host = VSPI_HOST;
    config.spi_mode = 0;
    config.freq_write = kDisplaySpiWriteHz;
    config.freq_read = kDisplaySpiReadHz;
    config.spi_3wire = false;
    config.use_lock = true;
    config.dma_channel = SPI_DMA_CH_AUTO;
    config.pin_sclk = 14;
    config.pin_mosi = 13;
    config.pin_miso = 12;
    config.pin_dc = 2;
    bus.config(config);
    panel.setBus(&bus);
  }

  {
    auto config = panel.config();
    config.pin_cs = 15;
    config.pin_rst = -1;
    config.pin_busy = -1;
    config.panel_width = kDisplayPanelWidth;
    config.panel_height = kDisplayPanelHeight;
    config.offset_x = kDisplayOffsetX;
    config.offset_y = kDisplayOffsetY;
    config.memory_width = kDisplayPanelWidth;
    config.memory_height = kDisplayPanelHeight;
    config.offset_rotation = 0;
    config.dummy_read_pixel = 8;
    config.dummy_read_bits = 1;
    config.readable = true;
    config.invert = kDisplayInvert;
    config.rgb_order = kDisplayRgbOrder;
    config.dlen_16bit = false;
    config.bus_shared = false;
    panel.config(config);
  }

  {
    auto config = light.config();
#if defined(CYD_VARIANT_ST7789)
    config.pin_bl = 27;
#else
    config.pin_bl = 21;
#endif
    config.invert = false;
    config.freq = 44100;
    config.pwm_channel = 7;
    light.config(config);
    panel.setLight(&light);
  }

  setPanel(&panel);

}   //   CydDisplay()

//--- LVGL flush callback that copies one area to the LCD
void DisplayDriver::flushDisplay(lv_disp_drv_t* displayDriver, const lv_area_t* area, lv_color_t* colorMap)
{
  const uint32_t width = static_cast<uint32_t>(area->x2 - area->x1 + 1);
  const uint32_t height = static_cast<uint32_t>(area->y2 - area->y1 + 1);

  tft.startWrite();
  tft.pushImage(area->x1, area->y1, width, height, reinterpret_cast<lgfx::rgb565_t*>(colorMap));
  tft.endWrite();

  lv_disp_flush_ready(displayDriver);

}   //   flushDisplay()

//--- Periodic 1 ms LVGL tick source
void DisplayDriver::tickTask(void* arg)
{
  static_cast<void>(arg);
  lv_tick_inc(1);

}   //   tickTask()

//--- Initialize LCD, LVGL and the frame buffer
bool DisplayDriver::begin()
{
  tft.init();
  tft.setRotation(kDisplayRotation);
  tft.setBrightness(255);

  const uint16_t screenWidth = tft.width();
  const uint16_t screenHeight = tft.height();

#if defined(TEST_DISPLAY)
  tft.fillScreen(0x0000);
  return true;
#endif

  lv_init();

  frameBuffer = static_cast<lv_color_t*>(heap_caps_malloc(
    screenWidth * 20 * sizeof(lv_color_t),
    MALLOC_CAP_DMA | MALLOC_CAP_INTERNAL
  ));

  if (frameBuffer == nullptr)
  {
    Serial.println("Error: LVGL draw buffer allocation failed");
    return false;
  }

  lv_disp_draw_buf_init(&drawBuffer, frameBuffer, nullptr, screenWidth * 20);
  lv_disp_drv_init(&displayDriver);
  displayDriver.hor_res = screenWidth;
  displayDriver.ver_res = screenHeight;
  displayDriver.flush_cb = flushDisplay;
  displayDriver.draw_buf = &drawBuffer;
  lv_disp_drv_register(&displayDriver);

  const esp_timer_create_args_t timerArgs =
  {
    .callback = &tickTask,
    .arg = nullptr,
    .dispatch_method = ESP_TIMER_TASK,
    .name = "lvglTick"
  };

  if (esp_timer_create(&timerArgs, &tickTimer) != ESP_OK)
  {
    Serial.println("Error: LVGL tick timer creation failed");
    return false;
  }

  if (esp_timer_start_periodic(tickTimer, 1000) != ESP_OK)
  {
    Serial.println("Error: LVGL tick timer start failed");
    return false;
  }

  return true;

}   //   begin()

//--- Run the LVGL timer handler regularly from loop()
void DisplayDriver::loop()
{
#if !defined(TEST_DISPLAY)
  lv_timer_handler();
#endif

}   //   loop()

//--- Draw paged diagnostics to identify compatible display driver settings
void DisplayDriver::runTestPattern()
{
#if defined(TEST_DISPLAY)
  static uint8_t page = 0;
  static uint32_t lastPageMs = 0;
  static uint8_t lastDrawnPage = 255;
  static constexpr uint32_t kTestPageIntervalMs = 4500;
  const uint32_t now = millis();

  if ((now - lastPageMs) >= kTestPageIntervalMs)
  {
    lastPageMs = now;
    page = static_cast<uint8_t>((page + 1) % 4);
  }

  if (page == lastDrawnPage)
  {
    return;
  }

  lastDrawnPage = page;

  const int16_t screenWidth = static_cast<int16_t>(tft.width());
  const int16_t screenHeight = static_cast<int16_t>(tft.height());

  tft.startWrite();

  if (page == 0)
  {
    const int16_t barWidth = screenWidth / 6;
    tft.fillRect(0 * barWidth, 0, barWidth, screenHeight, 0xF800);
    tft.fillRect(1 * barWidth, 0, barWidth, screenHeight, 0x07E0);
    tft.fillRect(2 * barWidth, 0, barWidth, screenHeight, 0x001F);
    tft.fillRect(3 * barWidth, 0, barWidth, screenHeight, 0xFFE0);
    tft.fillRect(4 * barWidth, 0, barWidth, screenHeight, 0xF81F);
    tft.fillRect(5 * barWidth, 0, screenWidth - (5 * barWidth), screenHeight, 0x07FF);
  }
  else if (page == 1)
  {
    for (int16_t y = 0; y < screenHeight; y++)
    {
      const uint8_t level = static_cast<uint8_t>((y * 255) / (screenHeight - 1));
      const uint16_t color = static_cast<uint16_t>(((level >> 3) << 11) | ((level >> 2) << 5) | (level >> 3));
      tft.drawFastHLine(0, y, screenWidth, color);
    }
  }
  else if (page == 2)
  {
    tft.fillScreen(0x0000);

    for (int16_t x = 0; x < screenWidth; x += 16)
    {
      tft.drawFastVLine(x, 0, screenHeight, 0x7BEF);
    }

    for (int16_t y = 0; y < screenHeight; y += 16)
    {
      tft.drawFastHLine(0, y, screenWidth, 0x7BEF);
    }

    tft.drawLine(0, 0, screenWidth - 1, screenHeight - 1, 0xF800);
    tft.drawLine(screenWidth - 1, 0, 0, screenHeight - 1, 0x001F);
    tft.drawRect(0, 0, screenWidth, screenHeight, 0xFFFF);

    //-- Corner markers help identify rotation without reading text
    const int16_t markerSize = 20;
    tft.fillRect(0, 0, markerSize, markerSize, 0xF800);
    tft.fillRect(screenWidth - markerSize, 0, markerSize, markerSize, 0x07E0);
    tft.fillRect(0, screenHeight - markerSize, markerSize, markerSize, 0x001F);
    tft.fillRect(screenWidth - markerSize, screenHeight - markerSize, markerSize, markerSize, 0xFFE0);
  }
  else
  {
    tft.fillScreen(0x0000);
    tft.setTextSize(2);
    tft.setTextColor(0xFFFF, 0x0000);
    tft.setCursor(8, 8);
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

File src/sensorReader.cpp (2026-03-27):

#include "sensorReader.h"
#include <Wire.h>
#include "appConfig.h"

//--- Initialize the SEN66 sensor and start continuous measurements
bool SensorReader::begin()
{
  Wire.begin(kI2cSdaPin, kI2cSclPin, 100000);

  sen66.begin(Wire, kSen66I2cAddress);

  const int16_t error = sen66.startContinuousMeasurement();

  if (error != 0)
  {
    char errorMessage[256];
    errorToString(error, errorMessage, sizeof(errorMessage));
    Serial.printf("Error: SEN66 startContinuousMeasurement failed: %s\n", errorMessage);
    return false;
  }

  Serial.println("SEN66 continuous measurement started");
  return true;

}   //   begin()

//--- Read all available measured values from the SEN66
bool SensorReader::read(SensorData& data)
{
  int16_t error = sen66.readMeasuredValues(
    data.pm1p0,
    data.pm2p5,
    data.pm4p0,
    data.pm10p0,
    data.humidity,
    data.temperature,
    data.vocIndex,
    data.noxIndex,
    data.co2
  );

  if (error != 0)
  {
    char errorMessage[256];
    errorToString(error, errorMessage, sizeof(errorMessage));
    Serial.printf("Warning: SEN66 read failed: %s\n", errorMessage);
    data.valid = false;
    return false;
  }

  data.valid = true;
  return true;

}   //   read()

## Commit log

2026-03-28 - Make sensor update interval configurable via UPDATE_INTERVAL define (default 2500ms) - Add dedicated showSensorError() method to display errors on all tiles - Improve last update text formatting (s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
    [appConfig.h, main.cpp]
2026-03-28 - Change SEN66 SDA pin from GPIO21 to GPIO27 to avoid conflict with ILI9341 backlight pin that caused black screen - Refactor header layout from flex to fixed positioning to prevent text jumping when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
    The GPIO21 pin conflict was causing display issues on ILI9341 variant. The header layout fix ensures stable text positioning regardless of content length changes. Temperature visualization now uses a simpler, more intuitive color ramp.
2026-03-28 feat: add MQTT publishing with WiFi portal configuration
    Add comprehensive MQTT support for publishing sensor data:
    - Integrate WiFiManager for on-demand captive portal configuration
    - Implement MQTT client with configurable broker, credentials, and topic
    - Add portal UI for MQTT settings (broker URL, port, credentials, publish interval)
    - Generate stable MQTT client ID from ESP32 MAC address
    - Publish JSON payload with PM, temperature, humidity, VOC, NOx, and CO2 readings
    - Add full-screen status messages for WiFi/MQTT portal feedback
    - Support GPIO0 long-press (10s) to clear WiFi settings
    [WiFiManagerExt.cpp, WiFiManagerExt.h, appConfig.h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]
2026-03-28 Version 1.0.0
    - Add visual MQTT connection indicator in dashboard header
    - Implement setMqttIndicator() method to show/hide MQTT status
    - Restructure header layout with dedicated status row
    - Add product images (SEN66 sensor, CYD board, pinout diagram)
    - Include example MQTT JSON payloads in README
    - Update timestamp format from ts_ms to ISO 8601 format
    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
2026-03-28 - Upgrade actions/checkout from v3 to v5 with full git history - Replace deprecated actions/create-release with GitHub API calls - Add comprehensive error handling (set -euo pipefail) - Improve relea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
    [main.cpp]
2026-03-29 - Add helper functions to generate device-specific AP names and MQTT topics based on MAC address - Add fallback logic for empty MQTT topic configuration - Reorganize assets: move images from Document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
2026-03-29 - Add applyDefaultTopicIfEmpty() helper to ensure MQTT topic defaults are consistently applied when empty - Add null terminators to MQTT config buffers for safer string handling - Improve WiFi connec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
2026-03-31 Added OpenSCAD files
    [YAPP_Template_v3.scad, YAPPgenerator_v3.scad, deskAerosolSensor.scad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]
2026-03-31 Small Fix to deskAerosolSensor.scad
    [deskAerosolSensor.scad, deskAerosolSensorBase.stl]
2026-04-10 Add ability to skip PlatformIO environments by including "skip" in their name. This allows developers to temporarily exclude certain build environments without removing them from platformio.ini.
    Changes:
    - Add `shouldSkipEnv()` function to filter environments containing "skip"
    - Update environment parsing to separate skipped and active environments
    - Display skipped environments in console output for visibility
    - Rename `[env:ili9341_r4]` to `[env:ili9341_r4_SKIP]` as example
    - Enhance git hooks with Python version date tracking and template repo detection
    - Bump createProjectStructure.py version to v2.2
    - Update assets and version dates across multiple files
2026-04-10 docs: update project metadata and improve documentation
    - Simplify long project names in English and Dutch translations
    - Add complete GitHub repository URL and blog post link
    - Fix typo "Cheap Yello Board" → "Cheap Yellow Display"
    - Improve markdown formatting with consistent paragraph spacing
    - Add projects/ directory to .gitignoreblog post.
    [main.cpp]
2026-04-17 docs: add safety disclaimer and update README documentation
    - Add comprehensive safety disclaimer warning about electrical hazards
    - Add "What it is" section with clearer project description
    The disclaimer emphasizes that this project involves potentially dangerous
    voltages and should only be attempted by qualified individuals. It clarifies
    the developer's non-liability position and warns users about the incremental
    nature of the software development.
